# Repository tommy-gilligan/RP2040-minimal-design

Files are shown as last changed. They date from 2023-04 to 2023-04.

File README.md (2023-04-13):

# RP2040 Minimal Design for JLCPCB
Based on [Minimal design example](https://datasheets.raspberrypi.com/rp2040/Minimal-KiCAD.zip) referenced in [Hardware design with RP2040: Using RP2040 microcontrollers to build boards and products](https://datasheets.raspberrypi.com/rp2040/hardware-design-with-rp2040.pdf).  Design updated for KiCAD 7 and manufacture/assembly at JLCPCB.

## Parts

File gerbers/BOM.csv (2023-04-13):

Comment | Designator | Footprint | LCSC Part Number
10u | C1,C2,C17 | Capacitor_SMD:C_0805_2012Metric | C15850
27p | C14,C15 | Capacitor_SMD:C_0402_1005Metric | C52923
100n | C3,C4,C5,C6,C7,C8,C10,C12,C13,C16 | Capacitor_SMD:C_0402_1005Metric | C126504
1u | C9,C11 | Capacitor_SMD:C_0402_1005Metric | C307331
MountingHole | H1,H2,H3,H4 | MountingHole:MountingHole_2.7mm_M2.5
Conn_02x18_Odd_Even | J1,J4 | Connector_PinHeader_2.54mm:PinHeader_2x18_P2.54mm_Vertical | C168945
Conn_01x02 | J2 | Connector_PinHeader_2.54mm:PinHeader_1x02_P2.54mm_Vertical | C124375
USB_B_Micro | J3 | RP2040_minimal:USB_Micro-B_Amphenol_10103594-0001LF_Horizontal_modified | C428495
DNF | R1 | Capacitor_SMD:C_0402_1005Metric
1k | R2,R5 | Capacitor_SMD:C_0402_1005Metric | C11702
27 | R3,R4 | Capacitor_SMD:C_0402_1005Metric | C274349
NCP1117-3.3_SOT223 | U1 | Package_TO_SOT_SMD:SOT-223-3_TabPin2 | C26537
W25Q128JVS | U2 | Package_SO:SOIC-8_5.23x5.23mm_P1.27mm | C97521
RP2040 | U3 | RP2040_minimal:RP2040-QFN-56 | C2040
ABLS-12.000MHZ-B4-T | Y1 | RP2040_minimal:Crystal_SMD_HC49-US | C110563

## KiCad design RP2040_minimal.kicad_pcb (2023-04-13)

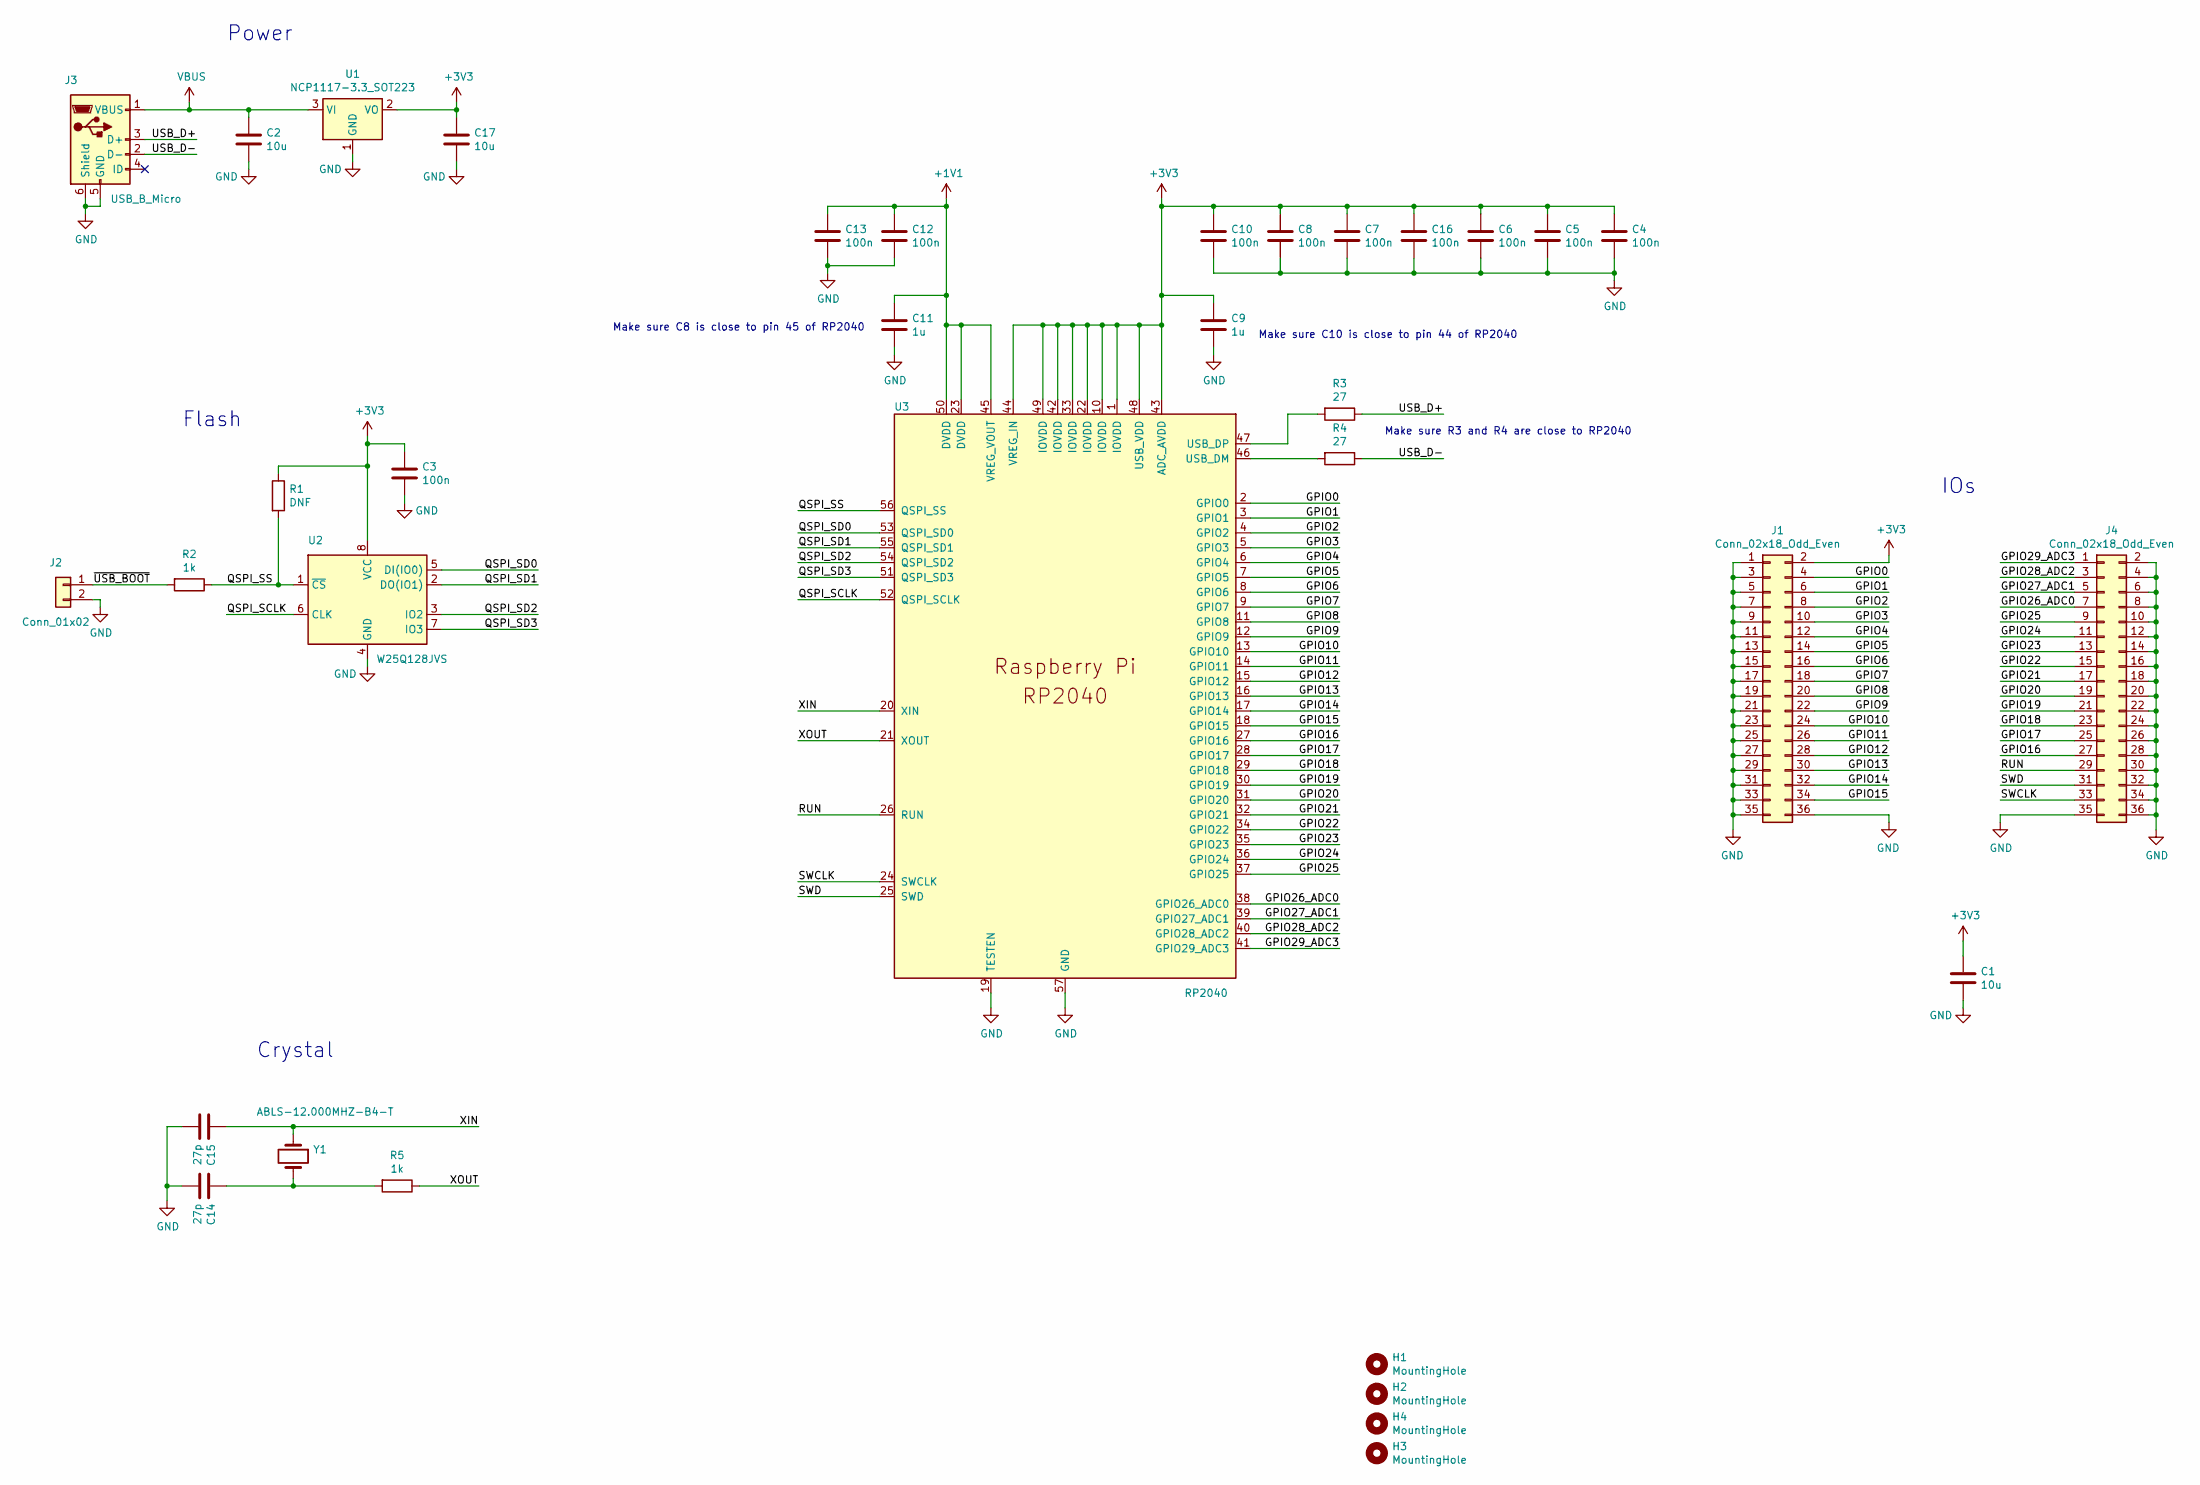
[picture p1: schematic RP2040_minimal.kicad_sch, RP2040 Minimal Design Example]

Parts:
C1, C2, C17: 10u; C_0805_2012Metric; LCSC C15850
C3, C4, C5, C6, C7, C8, C10, C12, C13, C16: 100n; C_0402_1005Metric; LCSC C126504
C9, C11: 1u; C_0402_1005Metric; LCSC C307331
C14, C15: 27p; C_0402_1005Metric; LCSC C52923
H1, H2, H3, H4: MountingHole; MountingHole_2.7mm_M2.5
J1, J4: Conn_02x18_Odd_Even; PinHeader_2x18_P2.54mm_Vertical; LCSC C168945
J2: Conn_01x02; PinHeader_1x02_P2.54mm_Vertical; LCSC C124375
J3: USB_B_Micro; USB_Micro-B_Amphenol_10103594-0001LF_Horizontal_modified; LCSC C428495
R1: DNF; C_0402_1005Metric
R2, R5: 1k; C_0402_1005Metric; LCSC C11702
R3, R4: 27; C_0402_1005Metric; LCSC C274349
U1: NCP1117-3.3_SOT223; SOT-223-3_TabPin2; LCSC C26537
U2: W25Q128JVS; SOIC-8_5.23x5.23mm_P1.27mm; LCSC C97521
U3: RP2040; RP2040-QFN-56; LCSC C2040
Y1: ABLS-12.000MHZ-B4-T; Crystal_SMD_HC49-US; LCSC C110563

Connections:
+1V1: C11.1, C12.1, C13.1, U3.23 (DVDD), U3.45 (VREG_VOUT), U3.50 (DVDD)
+3V3: C1.1, C3.1, C4.1, C5.1, C6.1, C7.1, C8.1, C9.1, C10.1, C16.1, C17.1, J1.2, R1.1, U1.2 (VO), U2.8 (VCC), U3.1 (IOVDD), U3.10 (IOVDD), U3.22 (IOVDD), U3.33 (IOVDD), U3.42 (IOVDD), U3.43 (ADC_AVDD), U3.44 (VREG_IN), U3.48 (USB_VDD), U3.49 (IOVDD)
/GPIO0: J1.4, U3.2 (GPIO0)
/GPIO1: J1.6, U3.3 (GPIO1)
/GPIO2: J1.8, U3.4 (GPIO2)
/GPIO3: J1.10, U3.5 (GPIO3)
/GPIO4: J1.12, U3.6 (GPIO4)
/GPIO5: J1.14, U3.7 (GPIO5)
/GPIO6: J1.16, U3.8 (GPIO6)
/GPIO7: J1.18, U3.9 (GPIO7)
/GPIO8: J1.20, U3.11 (GPIO8)
/GPIO9: J1.22, U3.12 (GPIO9)
/GPIO10: J1.24, U3.13 (GPIO10)
/GPIO11: J1.26, U3.14 (GPIO11)
/GPIO12: J1.28, U3.15 (GPIO12)
/GPIO13: J1.30, U3.16 (GPIO13)
/GPIO14: J1.32, U3.17 (GPIO14)
/GPIO15: J1.34, U3.18 (GPIO15)
/GPIO16: J4.27, U3.27 (GPIO16)
/GPIO17: J4.25, U3.28 (GPIO17)
/GPIO18: J4.23, U3.29 (GPIO18)
/GPIO19: J4.21, U3.30 (GPIO19)
/GPIO20: J4.19, U3.31 (GPIO20)
/GPIO21: J4.17, U3.32 (GPIO21)
/GPIO22: J4.15, U3.34 (GPIO22)
/GPIO23: J4.13, U3.35 (GPIO23)
/GPIO24: J4.11, U3.36 (GPIO24)
/GPIO25: J4.9, U3.37 (GPIO25)
/GPIO26_ADC0: J4.7, U3.38 (GPIO26_ADC0)
/GPIO27_ADC1: J4.5, U3.39 (GPIO27_ADC1)
/GPIO28_ADC2: J4.3, U3.40 (GPIO28_ADC2)
/GPIO29_ADC3: J4.1, U3.41 (GPIO29_ADC3)
/QSPI_SCLK: U2.6 (CLK), U3.52 (QSPI_SCLK)
/QSPI_SD0: U2.5 (DI(IO0)), U3.53 (QSPI_SD0)
/QSPI_SD1: U2.2 (DO(IO1)), U3.55 (QSPI_SD1)
/QSPI_SD2: U2.3 (IO2), U3.54 (QSPI_SD2)
/QSPI_SD3: U2.7 (IO3), U3.51 (QSPI_SD3)
/QSPI_SS: R1.2, R2.1, U2.1 (~CS), U3.56 (QSPI_SS)
/RUN: J4.29, U3.26 (RUN)
/SWCLK: J4.33, U3.24 (SWCLK)
/SWD: J4.31, U3.25 (SWD)
/USB_D+: J3.3 (D+), R3.1
/USB_D-: J3.2 (D-), R4.1
/XIN: C15.1, U3.20 (XIN), Y1.1
/XOUT: R5.1, U3.21 (XOUT)
/~USB_BOOT: J2.1, R2.2
GND: C1.2, C2.2, C3.2, C4.2, C5.2, C6.2, C7.2, C8.2, C9.2, C10.2, C11.2, C12.2, C13.2, C14.2, C15.2, C16.2, C17.2, J1.1, J1.3, J1.5, J1.7, J1.9, J1.11, J1.13, J1.15, J1.17, J1.19, J1.21, J1.23, J1.25, J1.27, J1.29, J1.31, J1.33, J1.35, J1.36, J2.2, J3.5 (GND), J3.6 (Shield), J4.2, J4.4, J4.6, J4.8, J4.10, J4.12, J4.14, J4.16, J4.18, J4.20, J4.22, J4.24, J4.26, J4.28, J4.30, J4.32, J4.34, J4.35, J4.36, U1.1 (GND), U2.4 (GND), U3.19 (TESTEN), U3.57 (GND)
unnamed: C14.1, R5.2, Y1.2
unnamed: R4.2, U3.46 (USB_DM)
unnamed: R3.2, U3.47 (USB_DP)
VBUS: C2.1, J3.1 (VBUS), U1.3 (VI)

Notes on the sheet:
IOs
Make sure C8 is close to pin 45 of RP2040
Make sure C10 is close to pin 44 of RP2040
Crystal
Power
Flash
Make sure R3 and R4 are close to RP2040

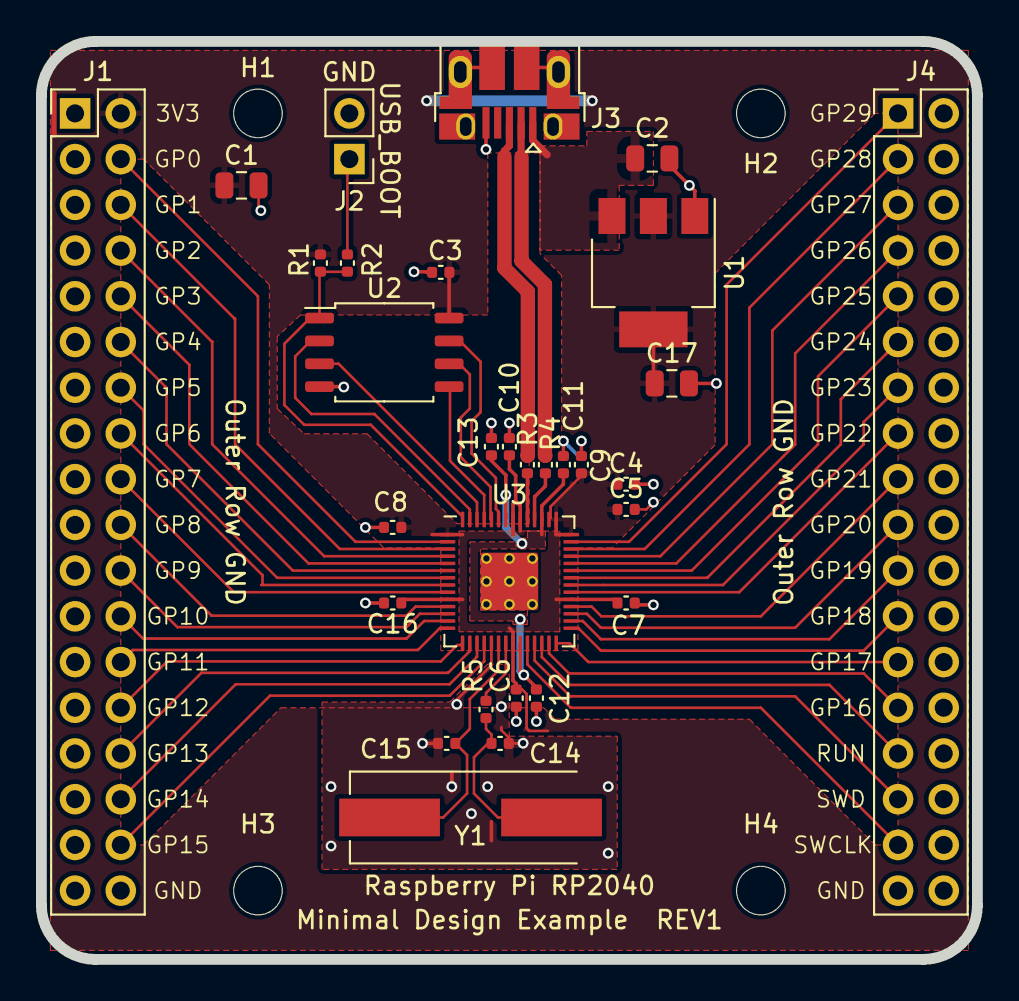
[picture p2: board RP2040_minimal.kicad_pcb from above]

Board: 2 copper layers, 52.0 x 51.0 mm, 34 parts (0 on the bottom side), 51 nets.

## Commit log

2023-04-13 initial checkin
    [RP2040_minimal.kicad_pcb, RP2040_minimal.sch]
2023-04-13 get DRC passing
    [RP2040_minimal.kicad_pcb, RP2040_minimal.kicad_sch]
2023-04-13 prepare fabrication outputs
    [BOM.csv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]
